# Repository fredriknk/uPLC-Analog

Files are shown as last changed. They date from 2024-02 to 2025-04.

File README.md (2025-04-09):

# μPLC - Analog
### Pcbway Sponsorship
Thanks so much to [PCBWay](https://www.pcbway.com/) who offered to assemble my first prototype batch of all three [uPLC modules](https://github.com/fredriknk/uPLC-stack). They deliver awesome quality as always, see the result for yourself below.

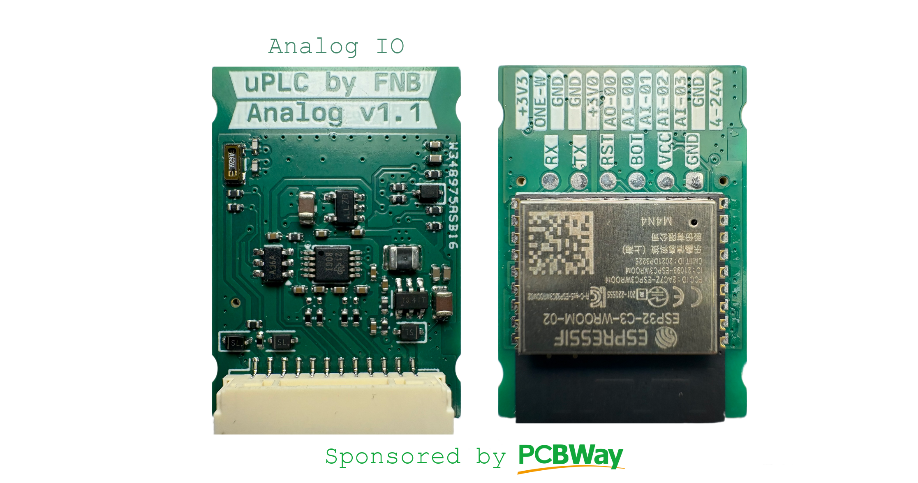
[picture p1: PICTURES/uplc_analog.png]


I now have two prototypes of the uPLC-Analog so ESP-Home integrations will come soon.

ESP micro PLC the size of a post stamp. The uPLC-analog version is an [ESP-32-C3](./DOCUMENTATION/esp-12f_product_specification_en.pdf) wifi, bluetooth module for communication and MCU, it has a 3.8-24V buck regulator, has four single ended / two differential 0-3V analog inputs through a [ADS1115](./DOCUMENTATION/ads1115.pdf), one 12 bit 3.6msps analog dac through a [MCP4725A0T](./DOCUMENTATION/Microchip-Tech-MCP4725A0T-E-CH_C144198.pdf) , and one protected 3.3v GPIO for onwire communication (Eg for DS18b20 sensors). The analog uPLC allso has input voltage monitoring for battery applications. 

[Schematic](./DOCUMENTATION/_schematic.pdf)

[Assembly IBOM](https://htmlpreview.github.io/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)

## Specifications
| **Parameter** | **Description** |
|---|---|
| _Input voltage_ | 3.8-24v |
| _Current_ | TBD Wifi: ##mA, Radio Off: ##mA, Deep sleep ##uA |  
| _Communication_ | 2.4ghz WIFI, Uart TTL |
| _Baudrate_ | 115200 |
| _PCB size_ | 22x31.4mm |
| _PCB info_ | 1.6mm FR4, HASL lead free, 4 layer |
| _Case size_ | XxXxXmm TBD |

## FIRST PRODUCTION PROTOTYPE
TODO

## Connector

| **Label** | **GPIO**|**Description** |
|---|-----|---|
|_3V3_ | 3V3 | 3.3v output for sensor connection |
|_ONE-W_ | GPIO18  | Protected gpio for onewire comm |
|_GND_ | GND | GND port for sensor connection|
|_GND_ | GND | GND port for sensor connection |
|_3V0_ | 3V0 | 3.0v rail for analog input connections |
|_AOUT0_ | DAC  | i2c DAC 0-3v3 analog Output  |
|_AIN0_ | ADC1  | i2c ADC 0-3v0 analog input  |
|_AIN1_ | ADC2  | i2c ADC 0-3v0 analog input  |
|_AIN2_ | ADC3  | i2c ADC 0-3v0 analog input  |
|_AIN3_ | ADC4  | i2c ADC 0-3v0 analog input  |
|_GND_ | GND |  Ground  |
|_4-24V_ | Buck reg |3.8-24v polarity protected power input |

## PCB Pictures
Pcb-assembly by [PCBWay](https://www.pcbway.com/)
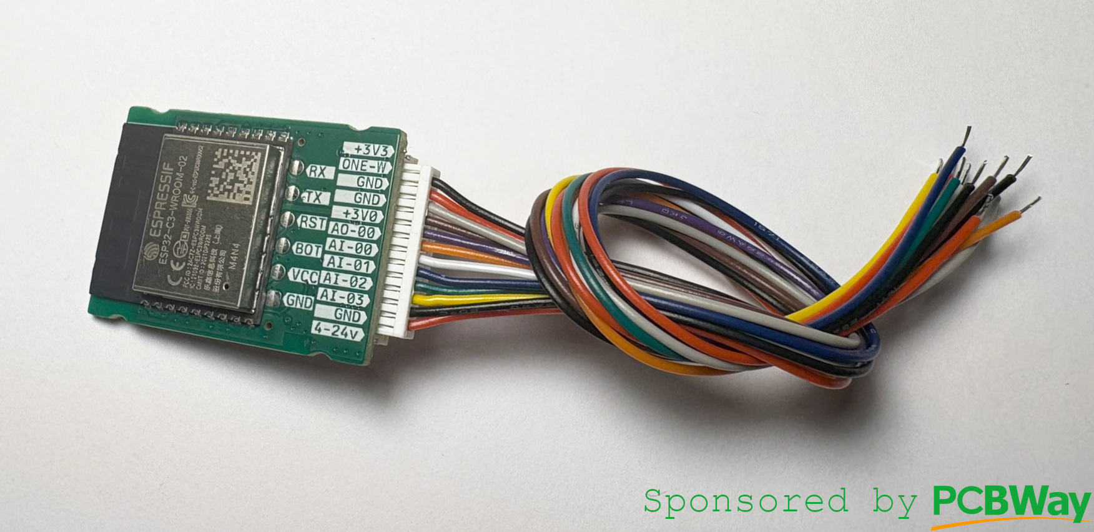
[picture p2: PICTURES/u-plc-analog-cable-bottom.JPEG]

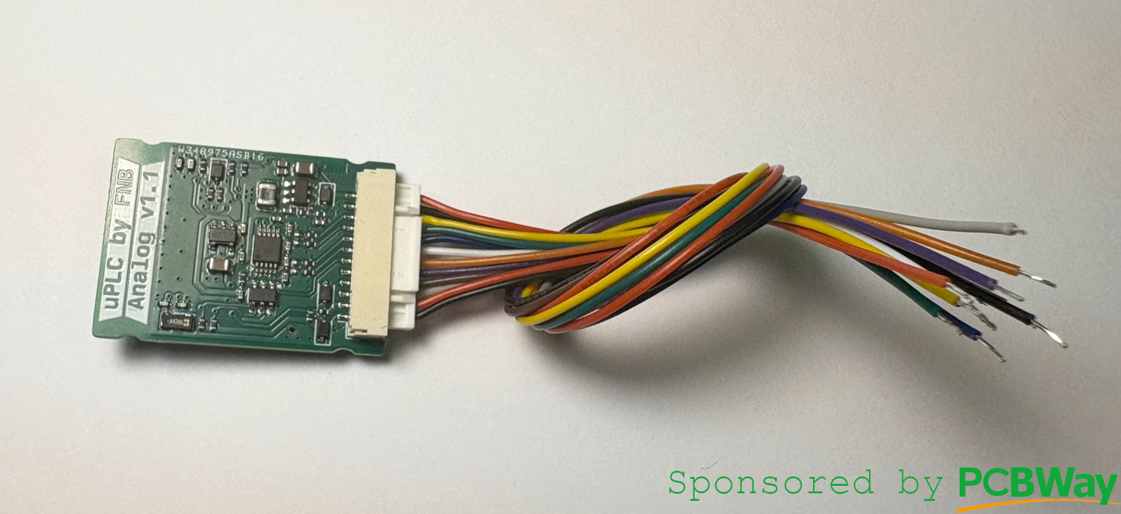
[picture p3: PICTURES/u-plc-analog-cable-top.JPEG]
Side

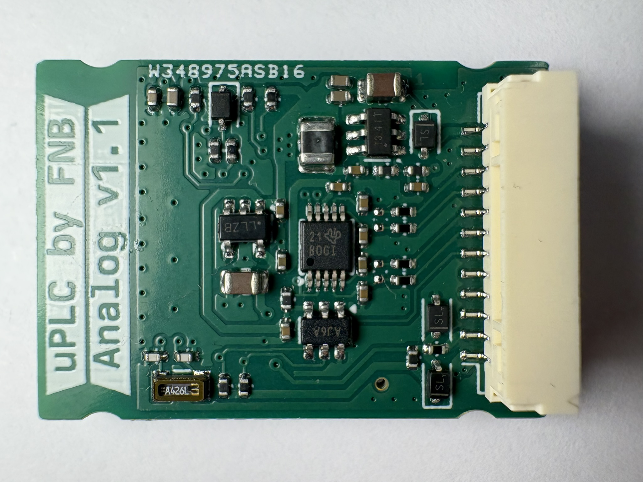
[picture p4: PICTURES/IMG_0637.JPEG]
Top

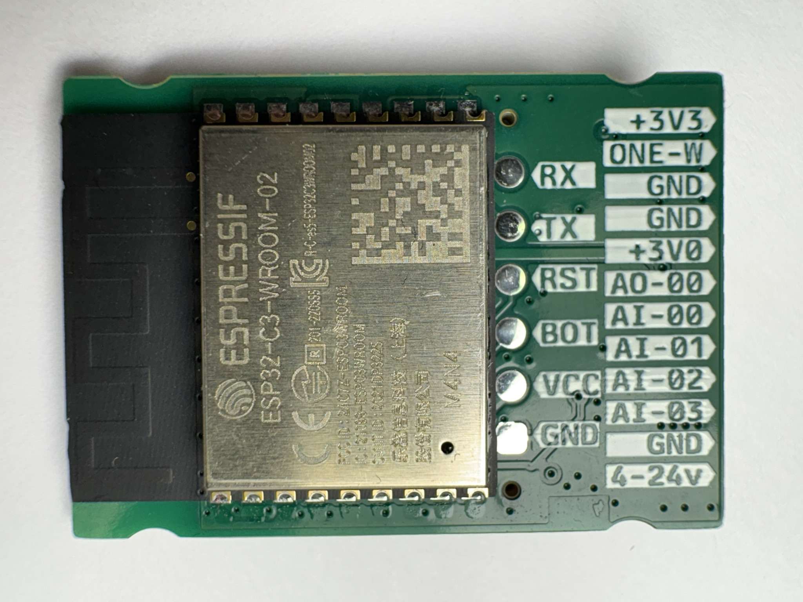
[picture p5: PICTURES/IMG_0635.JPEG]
Bototm


## Homeassistant Implementation
TODO

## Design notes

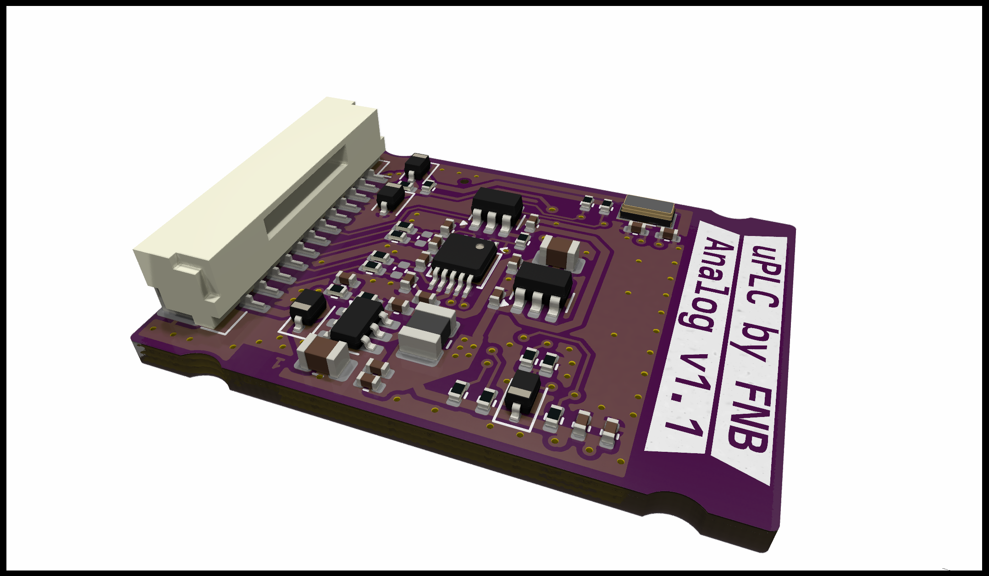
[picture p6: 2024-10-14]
PICTURES/TOP.PNG

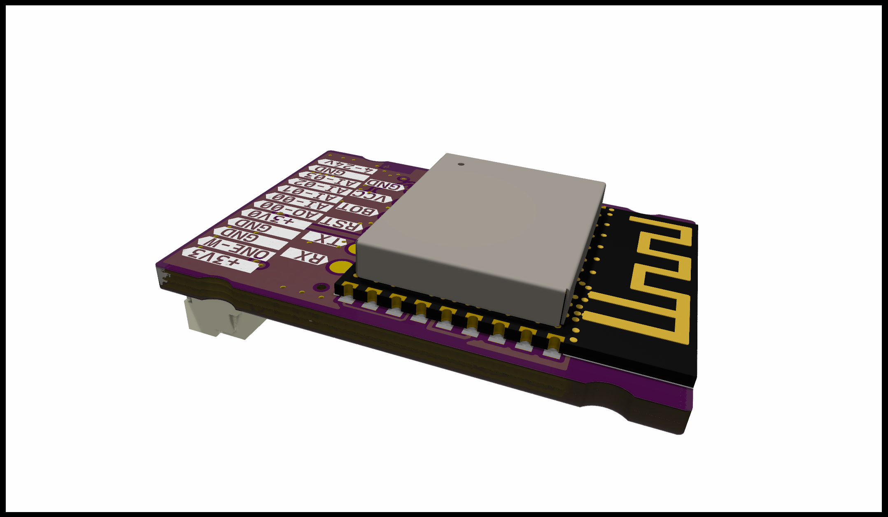
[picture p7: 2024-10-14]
PICTURES/BOTTOM.PNG

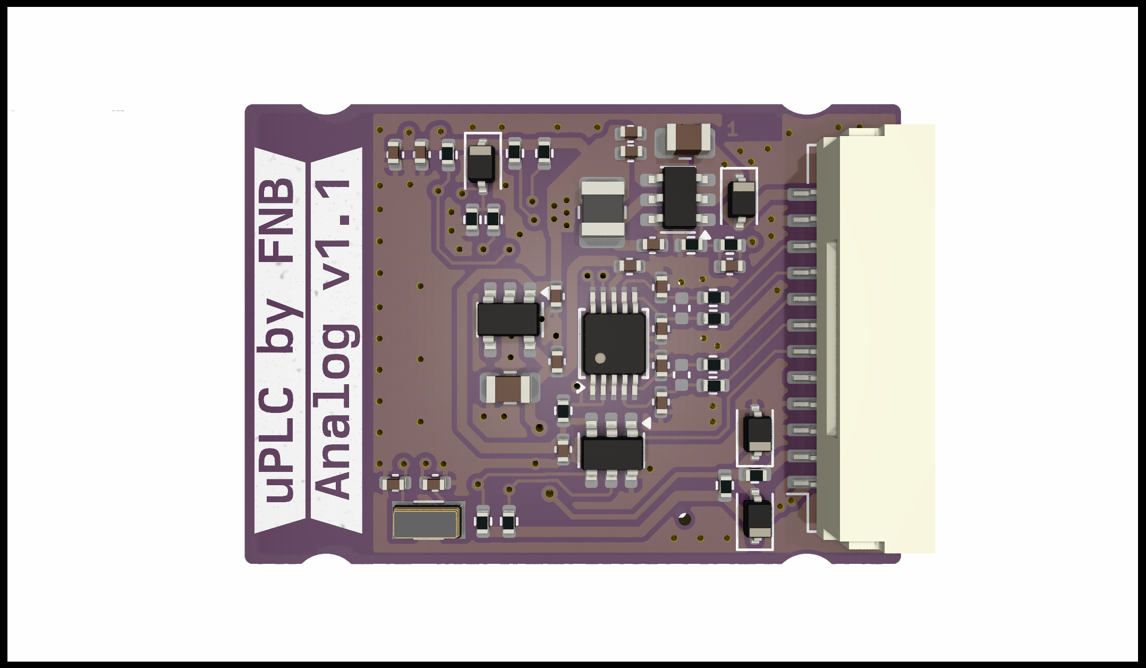
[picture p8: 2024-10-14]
PICTURES/OTOP.PNG

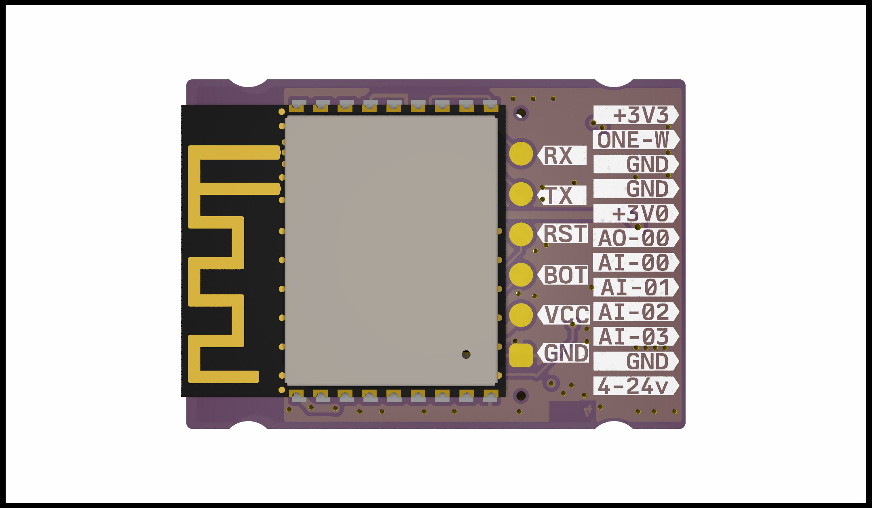
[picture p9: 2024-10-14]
PICTURES/OBOT.PNG

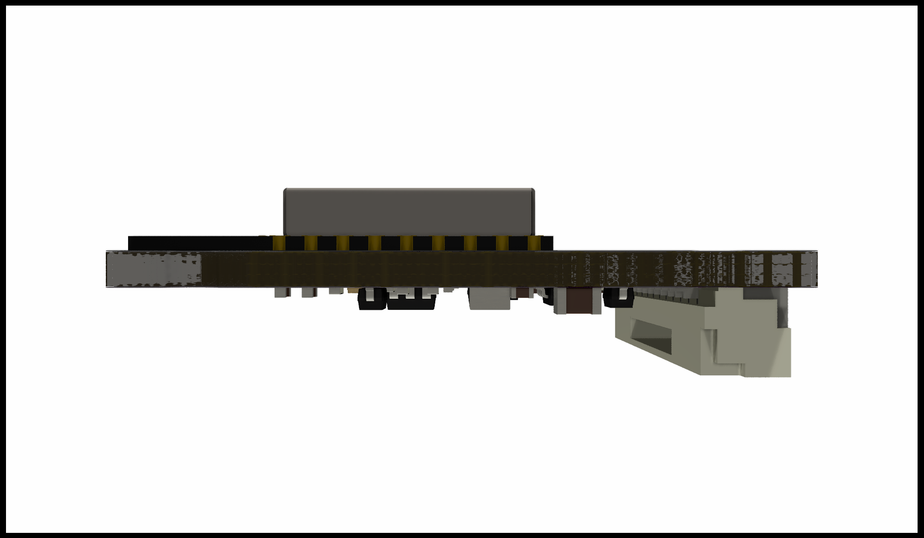
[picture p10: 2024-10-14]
PICTURES/OLEFT.png

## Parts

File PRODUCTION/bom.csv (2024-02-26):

Designator | Footprint | Quantity | Value | LCSC Part #
C1, C4 | 0402 | 2 | 20pf | C1554
C10, C13, C14, C15, C16, C17, C18, C2, C3, C6, C9 | 0402 | 11 | 0.1uF | C307331
C11, C12, C8 | 0402 | 3 | 22uf | C415703
C19, C20 | 0402 | 2 | 1uF | DNP
C5, C7 | 0805 | 2 | 10uF | C162422
D1, D2, D3, D4 | D_SOD-323 | 4 | 1N5819WS | C191023
J1 | TestPoint_Pad_1.0x1.0mm_6pad | 1 | Conn_01x06_Pin | DNP
J2 | JST_GH_SM12B-GHS-TB_1x12-1MP_P1.25mm_Horizontal | 1 | SM12B-GHS-TB(LF)(SN) | C265421
L1 | 1008 | 1 | 6.8uH | C98340
R1, R12, R16, R2, R3, R4, R5, R6 | 0402 | 8 | 10K | C25744
R10, R11, R8, R9 | 0402 | 4 | 499R | C25076
R13 | 0402 | 1 | 100R | C25076
R14 | 0402 | 1 | 182k | C11481
R15 | 0402 | 1 | 62k | C137950
R7 | 0402 | 1 | 309k
U1 | TSOT-23-6 | 1 | AP63201WU | C2071044
U2 | TSSOP-10_3x3mm_P0.5mm | 1 | ADS1115IDGS
U3 | ESP32-C3-WROOM-02 | 1 | ESP32-C3-WROOM-02 | C2934560
U4 | SOT-23-5 | 1 | LP5907MFX-3.0
U5 | SOT-23-6 | 1 | MCP4725xxx-xCH
Y1 | Crystal_SMD_3215-2Pin_3.2x1.5mm | 1 | 32.768khz 3215 12.5pf | C32346

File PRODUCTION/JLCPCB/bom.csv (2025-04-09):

Designator | Footprint | Quantity | Value | LCSC Part #
C1, C4 | 0402 | 2 | 20pf | C1554
C10, C13, C14, C15, C16, C17, C18, C19, C2, C20, C3, C6, C9 | 0402 | 13 | 0.1uF | C77020
C11, C12, C8 | 0402 | 3 | 22uf | C415703
C5, C7 | 0805 | 2 | 10uF | C162422
D1, D2, D3, D4 | D_SOD-323 | 4 | 1N5819WS | C191023
J1 | TestPoint_Pad_1.0x1.0mm_6pad | 1 | Conn_01x06_Pin | DNP
J2 | JST_GH_SM12B-GHS-TB_1x12-1MP_P1.25mm_Horizontal | 1 | SM12B-GHS-TB(LF)(SN) | C265421
L1 | 1008 | 1 | 4.7uH | C82314
R1, R12, R16, R2, R3, R4, R5, R6 | 0402 | 8 | 10K | C25744
R10, R11, R8, R9 | 0402 | 4 | 499R | C4125
R13 | 0402 | 1 | 100R | C25076
R14 | 0402 | 1 | 182k | C11481
R15 | 0402 | 1 | 62k | C137950
R7 | 0402 | 1 | 309k | C159040
U1 | TSOT-23-6 | 1 | AP63201WU | C2071044
U2 | TSSOP-10_3x3mm_P0.5mm | 1 | ADS1115IDGS | C37593
U3 | ESP32-C3-WROOM-02 | 1 | ESP32-C3-WROOM-02 | C2934560
U4 | SOT-23-5 | 1 | LP5907MFX-3.0 | C475492
U5 | SOT-23-6 | 1 | MCP4725xxx-xCH | C144198
Y1 | Crystal_SMD_3215-2Pin_3.2x1.5mm | 1 | 32.768khz 3215 12.5pf | C32346

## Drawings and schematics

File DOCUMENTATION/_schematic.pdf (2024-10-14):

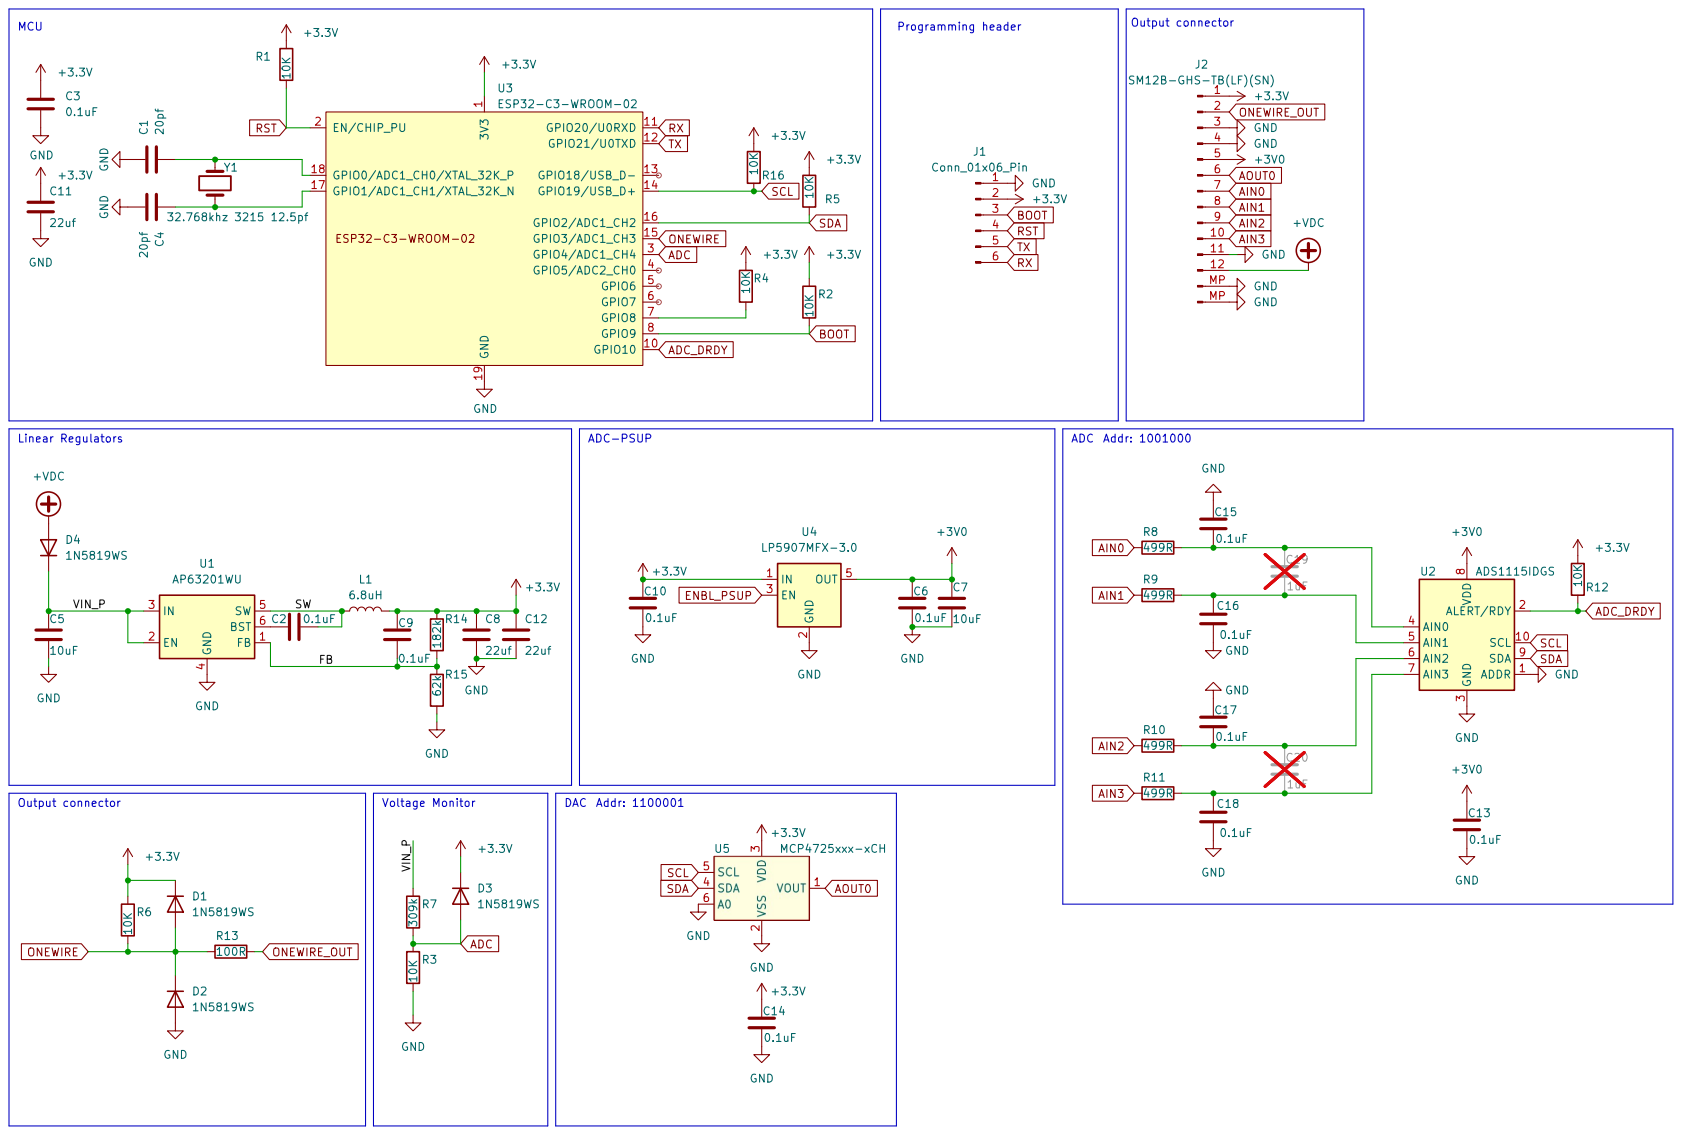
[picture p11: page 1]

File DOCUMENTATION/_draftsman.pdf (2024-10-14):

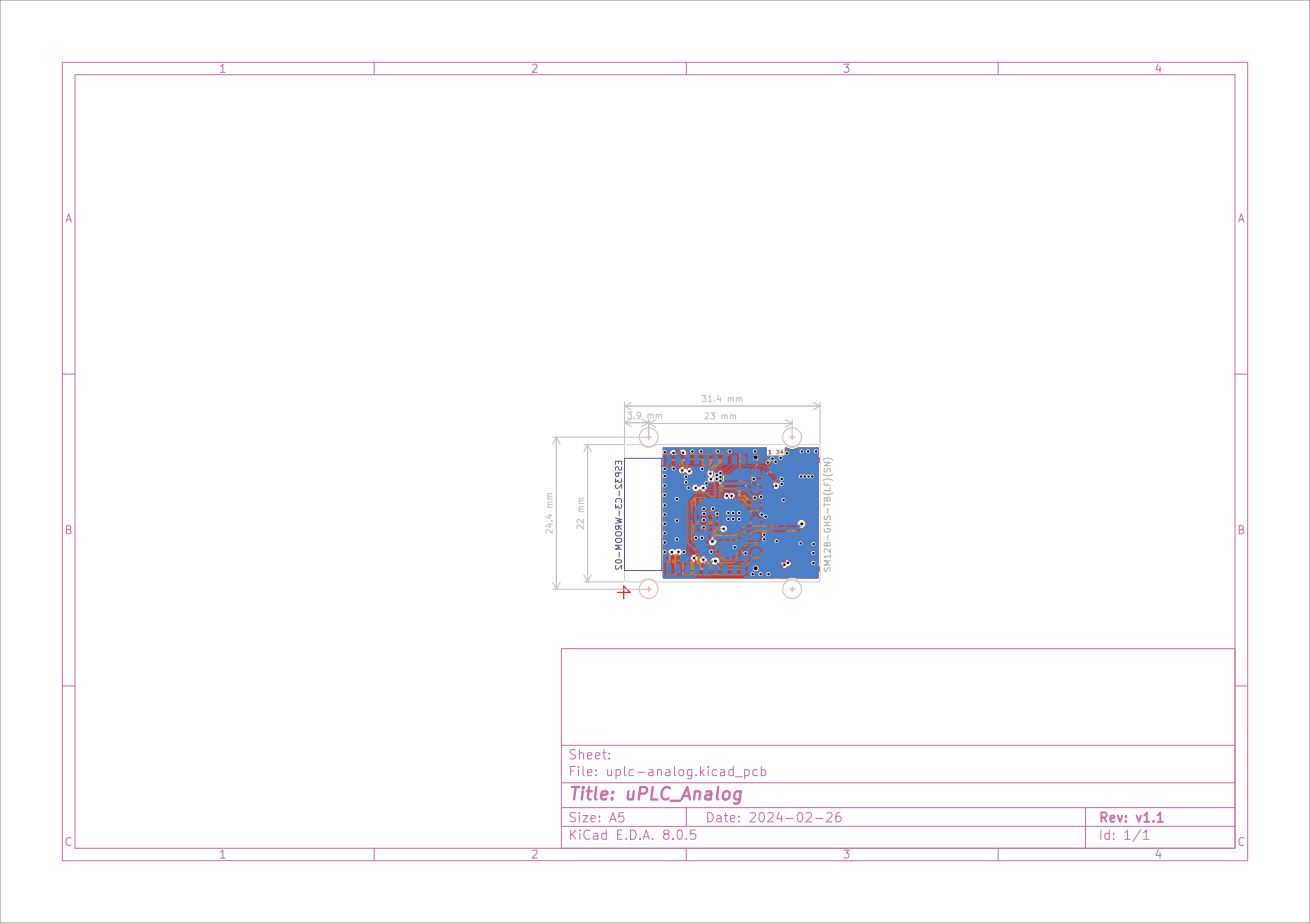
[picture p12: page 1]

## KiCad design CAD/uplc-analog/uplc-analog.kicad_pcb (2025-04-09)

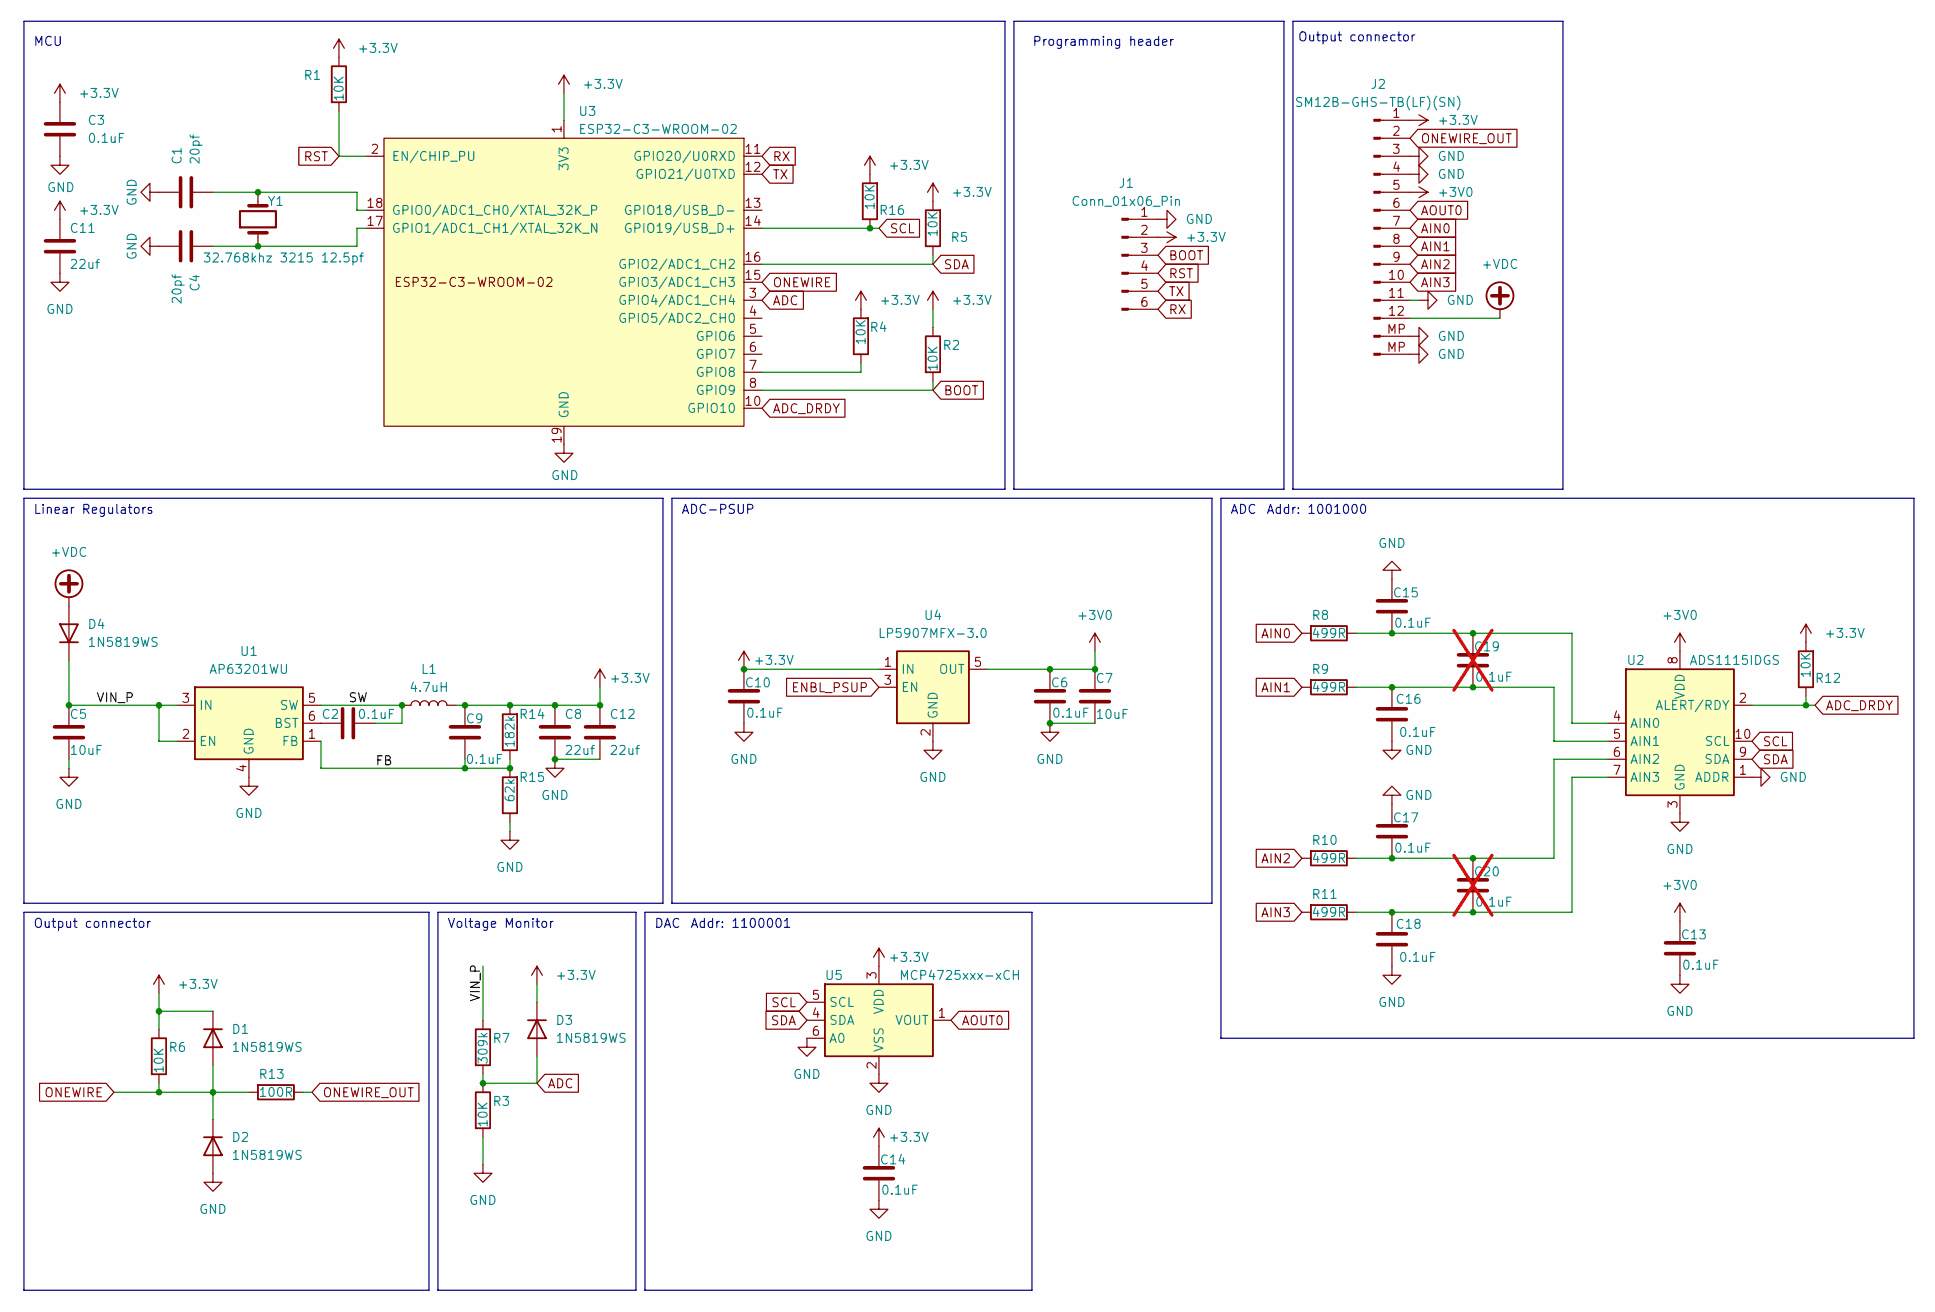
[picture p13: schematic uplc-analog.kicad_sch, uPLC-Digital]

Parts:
C1, C4: 20pf; C_0402_1005Metric; MPN 0402CG200J500NT; LCSC Part # C1554
C2, C3, C6, C9, C10, C13, C14, C15, C16, C17, C18: 0.1uF; C_0402_1005Metric; MPN GRM155R71H104KE14D; LCSC Part # C77020
C5, C7: 10uF; C_0805_2012Metric; MPN GRM21BR6YA106KE43L; LCSC Part # C162422
C8, C11, C12: 22uf; C_0402_1005Metric; MPN GRM155R60J226ME11D; LCSC Part # C415703
C19, C20: 0.1uF; C_0402_1005Metric; MPN GRM155R71H104KE14D; LCSC Part # C77020; not fitted
D1, D2, D3, D4: 1N5819WS; D_SOD-323; MPN 1N5819WS; LCSC Part # C191023
J1: Conn_01x06_Pin; TestPoint_Pad_1.0x1.0mm_6pad; LCSC Part # DNP
J2: SM12B-GHS-TB(LF)(SN); JST_GH_SM12B-GHS-TB_1x12-1MP_P1.25mm_Horizontal; MPN SM12B-GHS-TB(LF)(SN); LCSC Part # C265421
L1: 4.7uH; L_1008_2520Metric; MPN LQM2HPN4R7MG0L; LCSC Part # C82314
R1, R2, R3, R4, R5, R6, R12, R16: 10K; R_0402_1005Metric; MPN 0402WGF1002TCE; LCSC Part # C25744
R7: 309k; R_0402_1005Metric; MPN RTT023093FTH; LCSC Part # C159040
R8, R9, R10, R11: 499R; R_0402_1005Metric; MPN 0402WGF4990TCE; LCSC Part # C4125
R13: 100R; R_0402_1005Metric; MPN 0402WGF1000TCE; LCSC Part # C25076
R14: 182k; R_0402_1005Metric; MPN 0402WGF1823TCE; LCSC Part # C11481
R15: 62k; R_0402_1005Metric; MPN RC0402FR-0762KL; LCSC Part # C137950
U1: AP63201WU; TSOT-23-6; MPN AP63201WU-7; LCSC Part # C2071044
U2: ADS1115IDGS; TSSOP-10_3x3mm_P0.5mm; MPN ADS1115IDGSR; LCSC Part # C37593
U3: ESP32-C3-WROOM-02; MPN ESP32-C3-WROOM-02-N4; LCSC Part # C2934560
U4: LP5907MFX-3.0; SOT-23-5; MPN LP5907MFX-3.0/NOPB; LCSC Part # C475492
U5: MCP4725xxx-xCH; SOT-23-6; MPN MCP4725A0T-E/CH; LCSC Part # C144198
Y1: 32.768khz 3215 12.5pf; Crystal_SMD_3215-2Pin_3.2x1.5mm; MPN Q13FC13500004; LCSC Part # C32346

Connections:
+3.3V: C3.1, C8.1, C9.1, C10.1, C11.1, C12.1, C14.1, D1.1 (K), D3.1 (K), J1.2, J2.1, L1.2, R1.1, R2.1, R4.2, R5.2, R6.1, R12.2, R14.2, R16.2, U3.1 (3V3), U4.1 (IN), U5.3 (VDD)
+3V0: C6.1, C7.1, C13.1, J2.5, U2.8 (VDD), U4.5 (OUT)
+VDC: D4.2 (A), J2.12
/FB: C9.2, R14.1, R15.2, U1.1 (FB)
/SW: C2.1, L1.1, U1.5 (SW)
/VIN_P: C5.1, D4.1 (K), R7.1, U1.2 (EN), U1.3 (IN)
ADC: D3.2 (A), R3.1, R7.2, U3.3 (GPIO4/ADC1_CH4)
ADC_DRDY: R12.1, U2.2 (ALERT/RDY), U3.10 (GPIO10)
AIN0: J2.7, R8.2
AIN1: J2.8, R9.2
AIN2: J2.9, R10.2
AIN3: J2.10, R11.2
AOUT0: J2.6, U5.1 (VOUT)
BOOT: J1.3, R2.2, U3.8 (GPIO9)
ENBL_PSUP: U4.3 (EN)
GND: C1.1, C3.2, C4.2, C5.2, C6.2, C7.2, C8.2, C10.2, C11.2, C12.2, C13.2, C14.2, C15.1, C16.1, C17.1, C18.1, D2.2 (A), J1.1, J2.3, J2.4, J2.11, J2.MP (Pin_13), R3.2, R15.1, U1.4 (GND), U2.1 (ADDR), U2.3 (GND), U3.9 (GND), U3.19 (GND), U4.2 (GND), U5.2 (VSS), U5.6 (A0)
unnamed: C2.2, U1.6 (BST)
unnamed: C15.2, C19.1, R8.1, U2.4 (AIN0)
unnamed: C16.2, C19.2, R9.1, U2.5 (AIN1)
unnamed: C17.2, C20.1, R10.1, U2.6 (AIN2)
unnamed: C18.2, C20.2, R11.1, U2.7 (AIN3)
unnamed: C1.2, U3.18 (GPIO0/ADC1_CH0/XTAL_32K_P), Y1.2
unnamed: C4.1, U3.17 (GPIO1/ADC1_CH1/XTAL_32K_N), Y1.1
unnamed: R4.1, U3.7 (GPIO8)
ONEWIRE: D1.2 (A), D2.1 (K), R6.2, R13.2, U3.15 (GPIO3/ADC1_CH3)
ONEWIRE_OUT: J2.2, R13.1
RST: J1.4, R1.2, U3.2 (EN/CHIP_PU)
RX: J1.6, U3.11 (GPIO20/U0RXD)
SCL: R16.1, U2.10 (SCL), U3.14 (GPIO19/USB_D+), U5.5 (SCL)
SDA: R5.1, U2.9 (SDA), U3.16 (GPIO2/ADC1_CH2), U5.4 (SDA)
TX: J1.5, U3.12 (GPIO21/U0TXD)

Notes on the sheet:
ADC
Linear Regulators
MCU
Output connector
Addr: 1001000
Programming header
DAC
Addr: 1100001
Voltage Monitor
ADC-PSUP

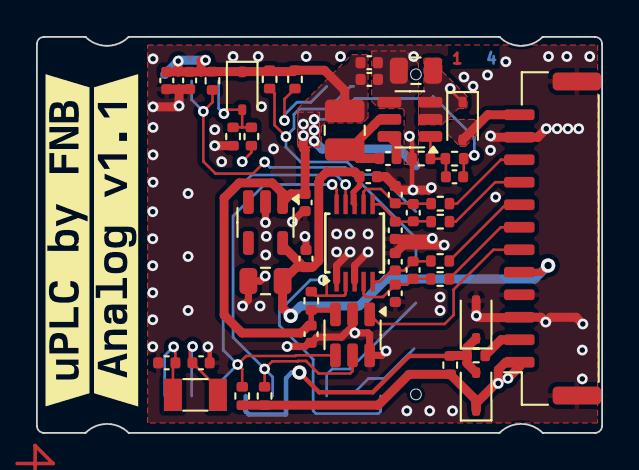
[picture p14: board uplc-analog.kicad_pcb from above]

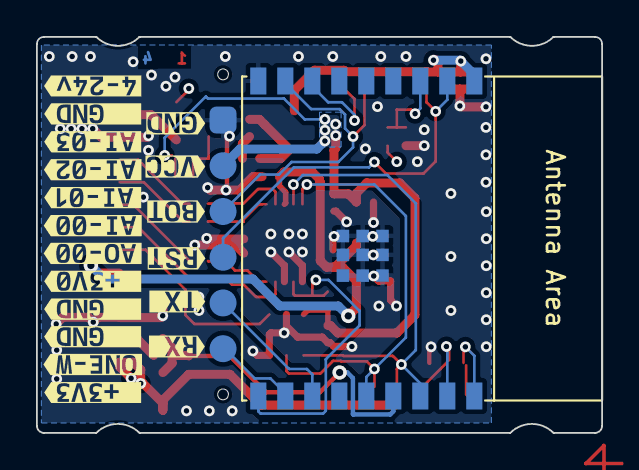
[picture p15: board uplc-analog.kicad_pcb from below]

Board: 4 copper layers, 31.4 x 22.0 mm, 69 parts (20 on the bottom side), 30 nets.

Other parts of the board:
kibuzzard-65D74DE1, kibuzzard-65D74DE1#2: G***; kibuzzard-65D74DE1
kibuzzard-65D74DEE: G***; kibuzzard-65D74DEE
kibuzzard-65D74DFB: G***; kibuzzard-65D74DFB
kibuzzard-65D460A0: G***; kibuzzard-65D460A0
kibuzzard-65D3616E: G***; kibuzzard-65D3616E
kibuzzard-65D7176D: G***; kibuzzard-65D7176D
kibuzzard-65D7177B: G***; kibuzzard-65D7177B
kibuzzard-65D36177: G***; kibuzzard-65D36177
kibuzzard-65D46022: G***; kibuzzard-65D46022
kibuzzard-65D46066: G***; kibuzzard-65D46066
kibuzzard-65D49092: G***; kibuzzard-65D49092
kibuzzard-65D71774: G***; kibuzzard-65D71774
kibuzzard-65DC95DA: G***; kibuzzard-65DC95DA
kibuzzard-65DC95E5: G***; kibuzzard-65DC95E5
kibuzzard-65DC95EF: G***; kibuzzard-65DC95EF
kibuzzard-65DC95F6: G***; kibuzzard-65DC95F6
kibuzzard-65DC961D: G***; kibuzzard-65DC961D
kibuzzard-65DC9610: G***; kibuzzard-65DC9610
kibuzzard-65DCE4DE: G***; kibuzzard-65DCE4DE

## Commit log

2024-02-26 first commit v1.1
    [bom.csv, designators.csv, positions.csv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]
2024-02-27 Rev 1.1
    [uplc-analog.kicad_pcb, uplc-analog.kicad_sch, uplc-digital.kicad_pcb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]
2024-10-14 Panelization changes
    [uplc-analog.kicad_pcb, uplc-analog.kicad_sch]
2024-10-14 Updated readme and documentation to analog
    [uplc-analog.kicad_pcb]
2025-04-09 feat: Production update
    [bom.csv, designators.csv, positions.csv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]
